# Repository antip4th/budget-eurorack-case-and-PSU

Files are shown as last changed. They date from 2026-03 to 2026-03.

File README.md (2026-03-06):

# budget-eurorack-case-and-PSU #
This repo contains all files to build your own budget 84HP Eurorack case with intrgrated bus board, PSU and an optional filter PCB.  

I made this, because of my limited budget as a student, I could not afford 250+€ 84HP cases and power supplies. Also I liked the idea to build stuff myself :)  

The case features two MeanWell PSUs, each of which supplies up to 3 A. This should be more than enough for a 84 HP case. Only +-12 V supplies, no +5 V. The cost is about 150 € max. Less, if you already have some cables and screws.

To remove the PSU output voltage spikes, I designed a custom filter PCB. It consists of one pi-filter per PSU [(see schematic)](PSU_filter_pcb/docs/psu_filter_schematic.pdf). It also can be built nicely on prototyping board instead of the PCB.

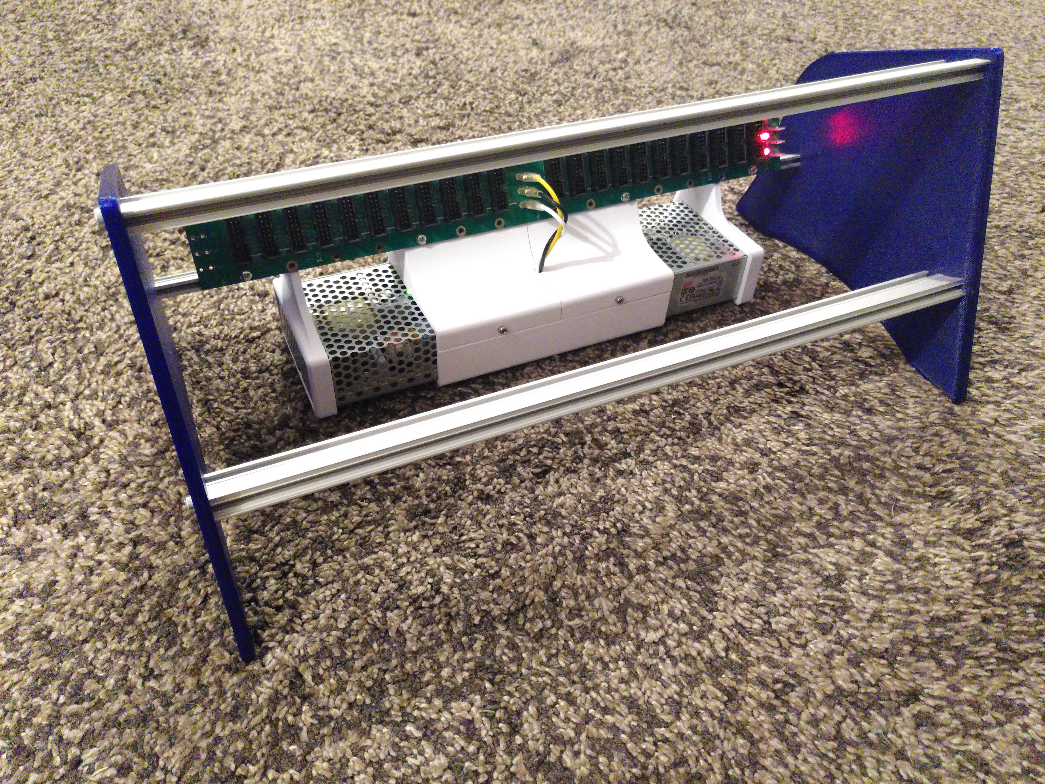
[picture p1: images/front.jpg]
Case front View


## Performance
The power supply together with the filter PCB can offer up to 3 A per power rail. In my setup I could only test with up to 2 A per rail. Because of the series resistance in the filter, at 2 A the supply voltage drops by about 120 mV. If tuning the PSU output voltage to slightly more than 12 V, the resulting voltage is still close to +-12 V, even under load. Some ripple switching voltage at around 500 Hz remains with about 10 mV peak to peak.  

## BOM Case ## 
|Part  |Quantity  |Price  (Feb. 2026)  | Link |
|---|---|---|---|
| Mean Well RS-35-12 PSU | 2 | 13.36 € | [DigiKey](https://www.digikey.de/en/products/detail/mean-well-usa-inc/RS-35-12/7706181) |
| Doepfer Bus board V6 | 1 | 40 € | [Schneidersladen](https://schneidersladen.de/en/doepfer-a-100-bus-board-v6) |
| 84HP eurorack rails with lip | 2 | 9 € | [Schneidersladen](https://schneidersladen.de/en/divers-sb-rail-19-with-lip) |
| 84 HP eurorack rails without lip | 1 | 10 € | [Schneidersladen](https://schneidersladen.de/en/divers-sb-rail-19-without-lip) |
| M3 slider nuts| 1 | 10 € | [Schneidersladen](https://schneidersladen.de/en/frap-tools-sliding-nuts-100-pcs) |
| Module Screws | 1 | 6 € | [Schneidersladen](https://schneidersladen.de/en/frap-tools-m3x6-philips-panhead-screws-silver-100-pieces) |
| M5x25 or M5x20 socket head screws | 6 | Included with rails if you order from Schneidersladen | [Amazon](https://a.co/d/07VXTLld) |
| | | ~ 8.00 € otherwise | |
| M3x6 socket head screw | 6 | | | 
| M3x5 button head screw | 2-8 | | |
| AC Cold appliances built-in plug | 1 | ~ 8 € | [Amazon](https://amzn.eu/d/06RYOiwI) |
| 0.75 mm²/18 AWG silicone cable | 1 m | 13 € | [Amazon](https://amzn.eu/d/0fPG9uPr) |
| Insulated cable lugs | 1 | 7 € | [Amazon](https://amzn.eu/d/0cKYAwAh) |
| Fork wire terminals | 1 | 7 € | [Amazon](https://amzn.eu/d/0jiY2vDV) |
| 3D-printed parts | | 3 € | |
| some heatshrink tubing | | | |
| SUM | | ~ 150 € worst case | |  

## BOM Filter PCB ##
|Part  |Quantity  |Price  (Feb. 2026)  | Link |
|---|---|---|---|
| Low ESR electrolytic caps 1000 µF | 4 | 0.5 € | [reichelt](https://www.reichelt.com/de/en/shop/product/elko_radial_1000_f_25_v_105_low_esr_12_5x20_mm_rm_5-166391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)|
| Ceramic caps 100 nF | 4 | 0.1 € | [reichelt](https://www.reichelt.com/de/en/shop/product/smd_multilayer_ceramic_capacitor_100_n_10_-22889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) |
| Ferrite core inductor 10 μΗ | 2 | 1 € | [reichelt](https://www.reichelt.com/de/en/shop/product/vertical_inductor_09hcp_ferrite_10_h-138644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) |
| Custom PCB or prototyping board | 1 | ~15 € if you have the PCB manufactured | |
| SUM | | ~ 20 € | |

## Build Instructions

### PCB

The soldering process is quite straight forward. I went for solder pads instead of terminal blocks to minimize contact resistance. Because of the big copper planes, for soldering the wires, I had to turn my soldering iron up to 450 °C.

<p align="center">
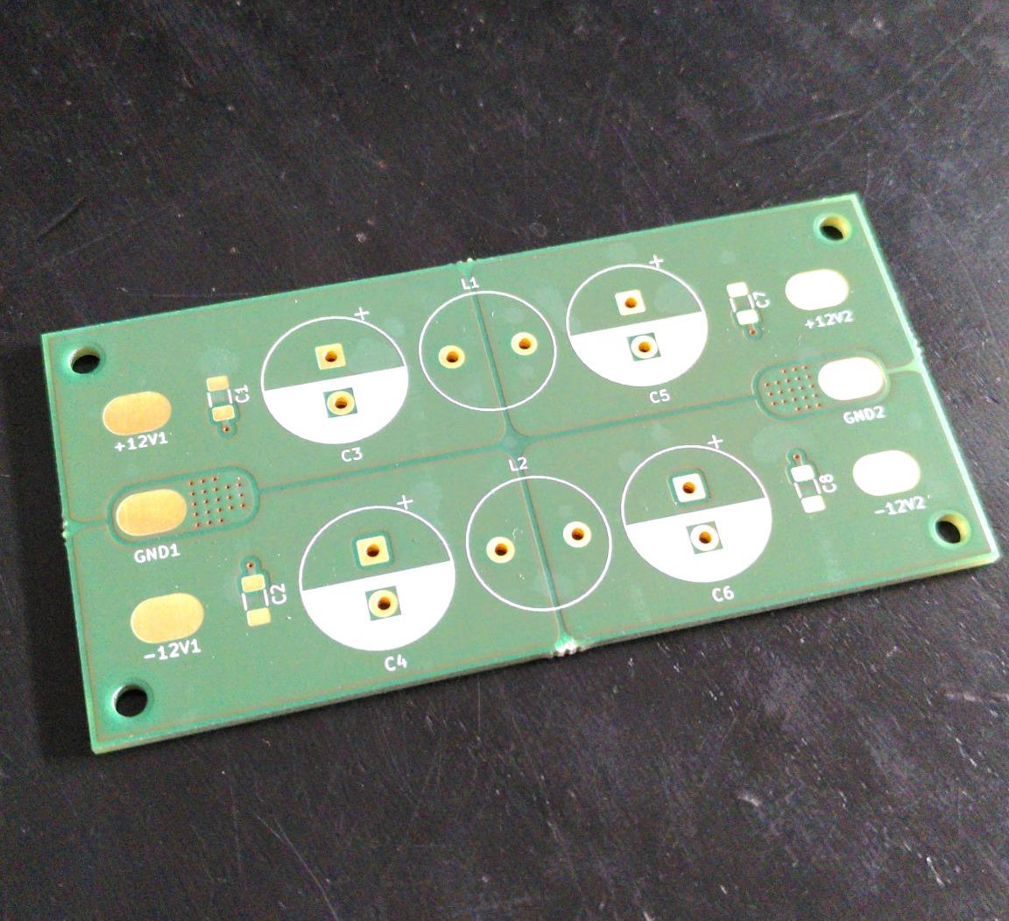
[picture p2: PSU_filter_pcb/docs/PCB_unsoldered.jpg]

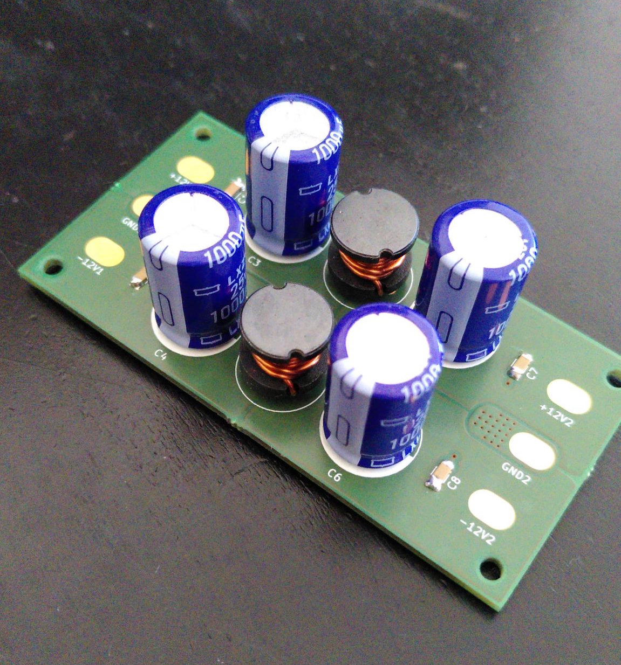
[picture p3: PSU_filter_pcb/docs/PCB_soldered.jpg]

</p>

<p align="center">

</p>

### Case

> [!CAUTION]
> This build requires wiring of mains power. Only work with mains voltage, if you know what you are doing!  
> Improper handling can cause electric shock, fire, or death. No liability is accepted for damage or injury.

1. The build starts with the wiring. The wire colors in this text correspond to the colors I used in my build and can be seen in the photos.
  1. Use the fork wire terminals to, connect the mains L (red), P (blue) and PE (green) terminals form the AC cold appliance socket with the respective terminals on both PSUs. The PSUs should be  connected to mains **in parallel**. You need to squeeze two cables into one cable lug.
  2. To get +-12 V outputs, the `-V` terminal of one of the PSUs is connected to the `+V` terminal of the other one. This node is the ground rail for the +-12 V outputs. I soldered both GND cables (black) onto the PCB's GND pad. If you don't use the PCB, directly crimp the bus board connector.
  3. The remaining `+V` output is the +12 V rail (yellow), and the remaining `-V` output is the -12 V rail (white). Either connect them to the PCB or crimp the connectors for the bus board directly.
  4. If you use the PCB, solder the cables on the output side and crimp the bus board connectors.

<p align="center">


</p>

2. Once the wiring is done, put everything together in the PSU case. Fix the PSUs to the case with the two screws on the bottom side. **Use short screws (<= 5mm) for this or you risk pushing the screw against the PCB inside the PSU!**

<p align="center">

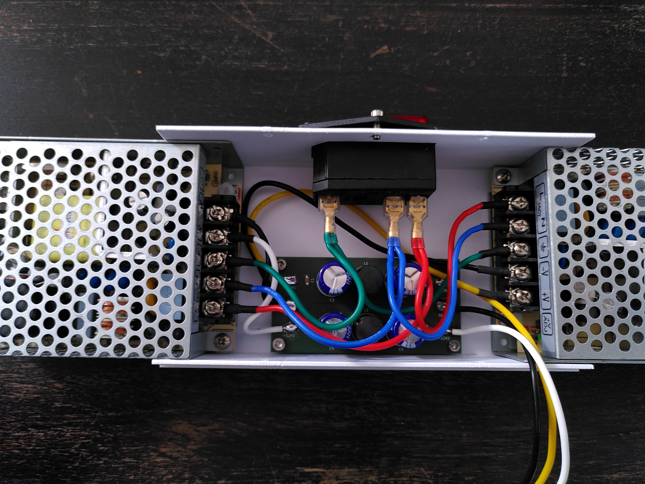
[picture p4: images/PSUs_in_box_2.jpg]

</p>

3. Attach the lid parts and the rib parts to the rail **without lip**. Use some of the screws and slider nuts for later fixing the position of the parts on the rail. 

<p align="center">
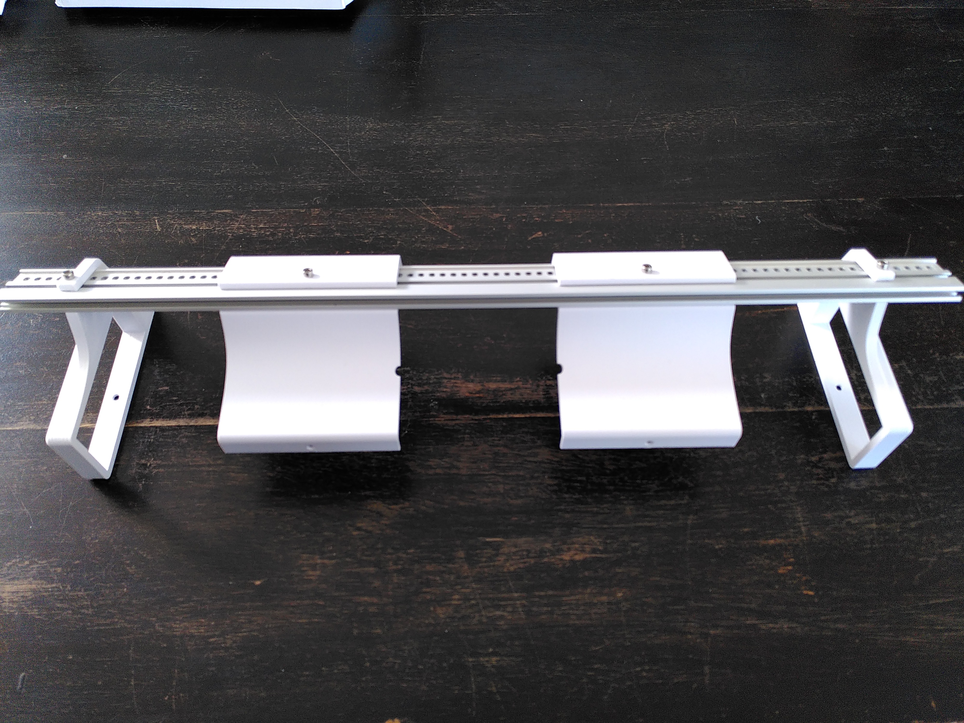
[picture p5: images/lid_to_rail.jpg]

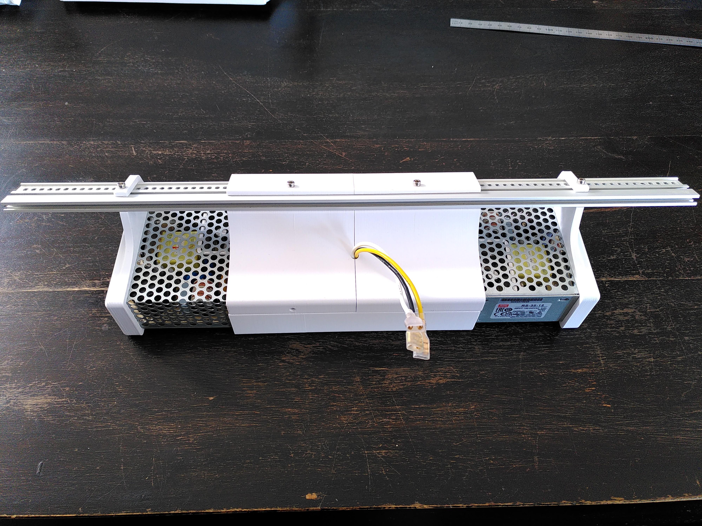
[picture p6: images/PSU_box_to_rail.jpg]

</p>

4. Attach the bus board to the rails with slider nuts. Put the ends of the PSUs into the ribs. Close everything up. Attach the side panels and the other rails and you're done!

<p align="center">
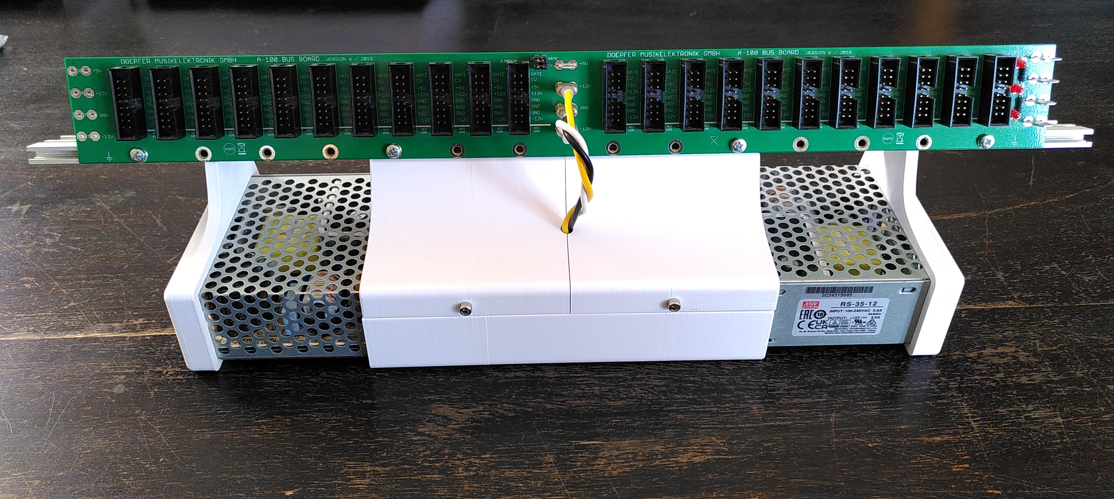
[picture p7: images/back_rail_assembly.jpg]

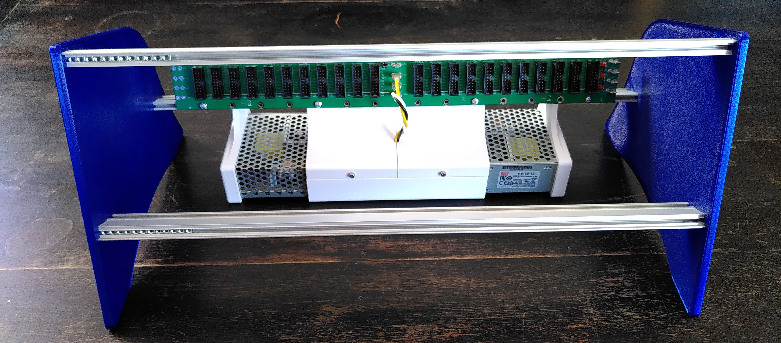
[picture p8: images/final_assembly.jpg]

</p>

## License

The contents of this repo are available under CERN OHL-S license.

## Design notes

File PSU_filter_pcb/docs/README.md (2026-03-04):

# README.md
This Project was generated with KiCad 9.0.7

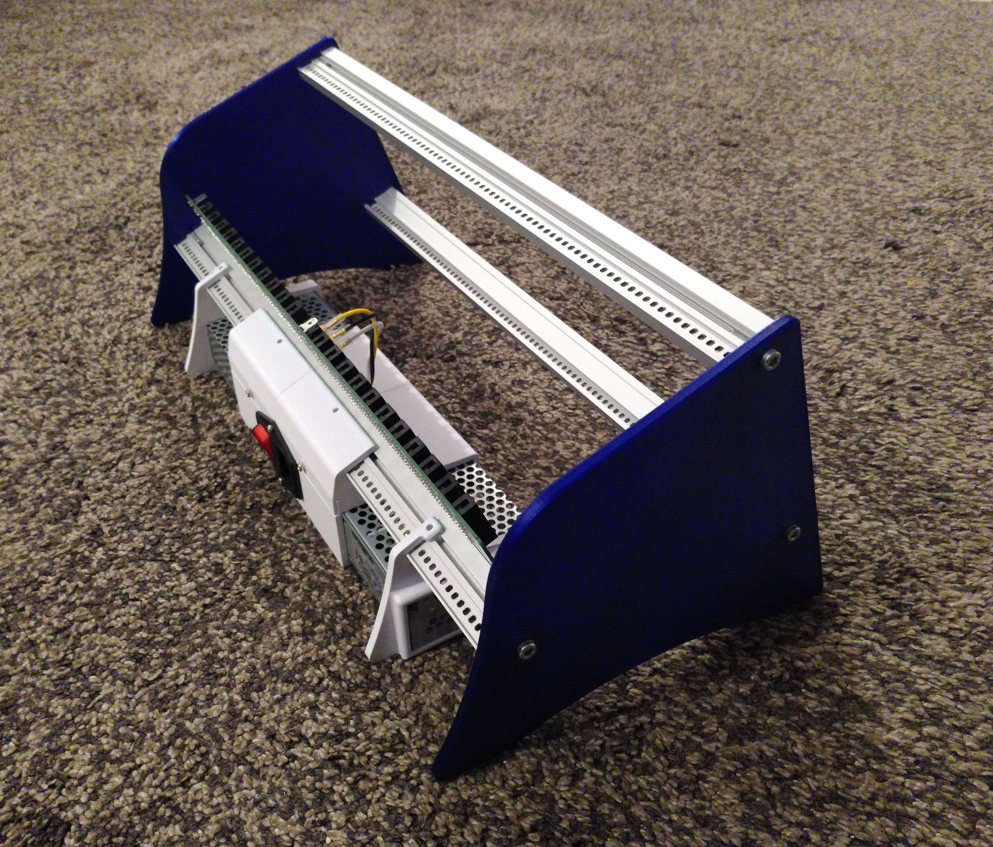
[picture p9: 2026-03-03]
images/rear_left.jpg

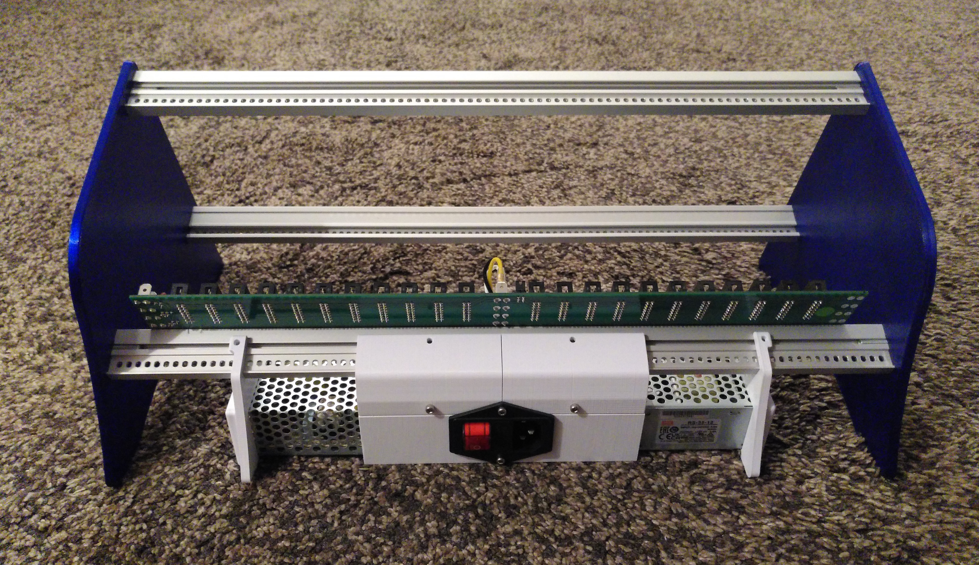
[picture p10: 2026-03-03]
images/rear.jpg

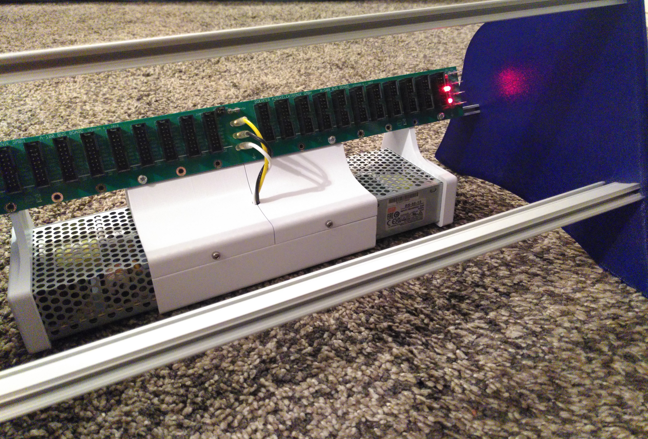
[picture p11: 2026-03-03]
images/front_closeup.jpg

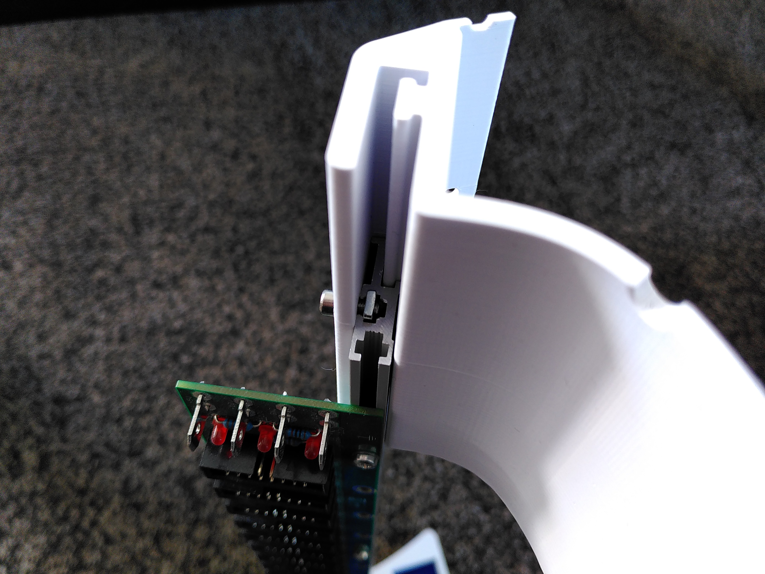
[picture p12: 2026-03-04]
images/lid_to_rail_nut.jpg

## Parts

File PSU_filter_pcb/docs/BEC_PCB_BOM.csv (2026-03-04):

Reference | Qty | Value | DNP | Exclude from BOM | Exclude from Board | Footprint | Datasheet
+12V1,+12V2,-12V1,-12V2,GND1,GND2 | 6 | TestPoint |  |  |  | Connector_Pad:WirePad_L6mm_W4mm | ~
C1,C2,C7,C8 | 4 | 100n |  |  |  | Capacitor_SMD:C_1206_3216Metric_Pad1.33x1.80mm_HandSolder | ~
C3,C4,C5,C6 | 4 | 1000u |  |  |  | Capacitor_THT:CP_Radial_D13.0mm_P5.00mm | ~
L1,L2 | 2 | 10u |  |  |  | Inductor_THT:L_Radial_D12.5mm_P7.00mm_Fastron_09HCP | ~

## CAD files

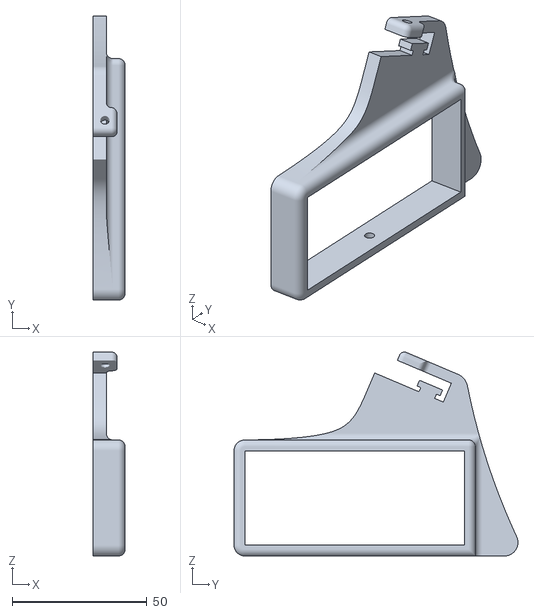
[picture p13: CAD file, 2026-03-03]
3d_print_parts/BudgetEurorackCase - PSURib.stl
12.0 x 105.3 x 75.6

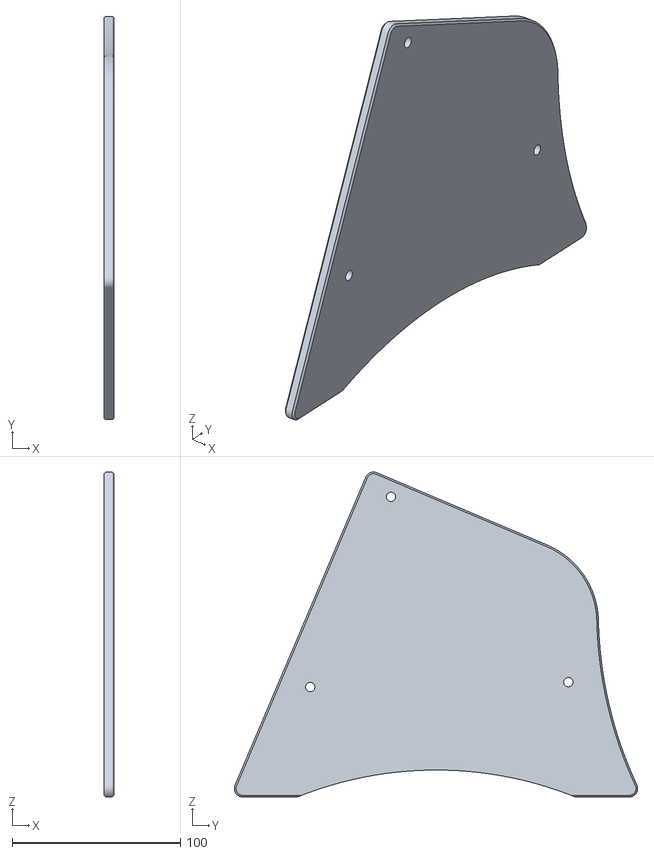
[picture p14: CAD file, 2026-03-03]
3d_print_parts/BudgetEurorackCase - sidePanel.stl
6.00 x 239.5 x 192.9

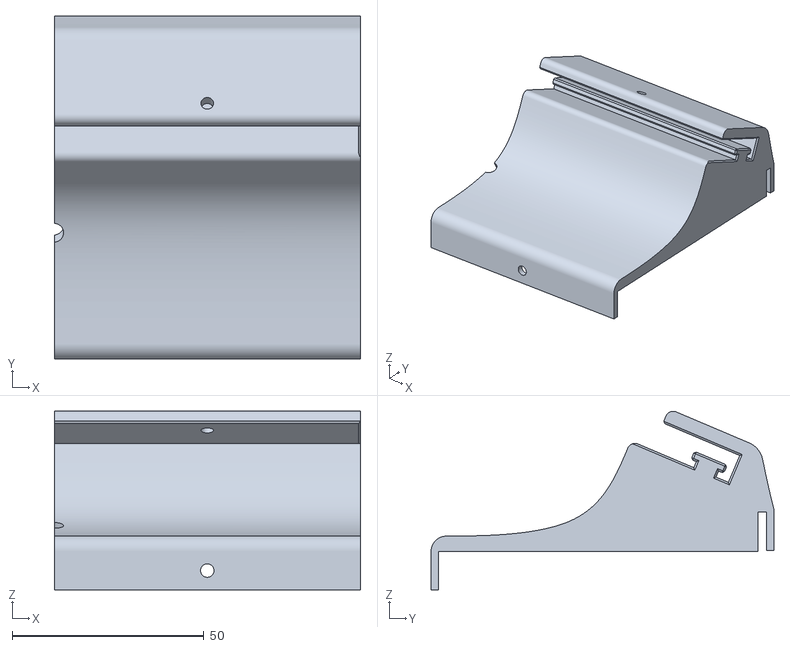
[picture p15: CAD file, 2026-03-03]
3d_print_parts/BudgetEurorackCase - PSUBoxLidRight.stl
79.9 x 89.5 x 46.6

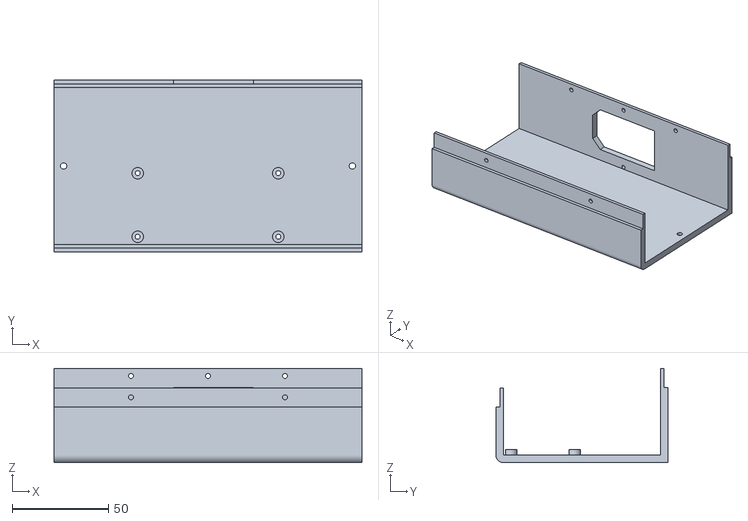
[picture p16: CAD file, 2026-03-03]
3d_print_parts/BudgetEurorackCase - PSUBoxBottom.stl
160.0 x 89.5 x 49.1

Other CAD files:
3d_print_parts/BudgetEurorackCase - PSUBoxLidLeft.stl

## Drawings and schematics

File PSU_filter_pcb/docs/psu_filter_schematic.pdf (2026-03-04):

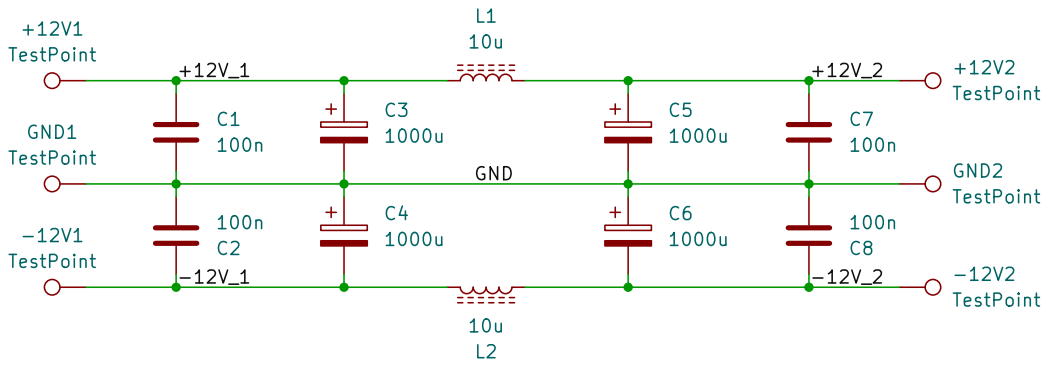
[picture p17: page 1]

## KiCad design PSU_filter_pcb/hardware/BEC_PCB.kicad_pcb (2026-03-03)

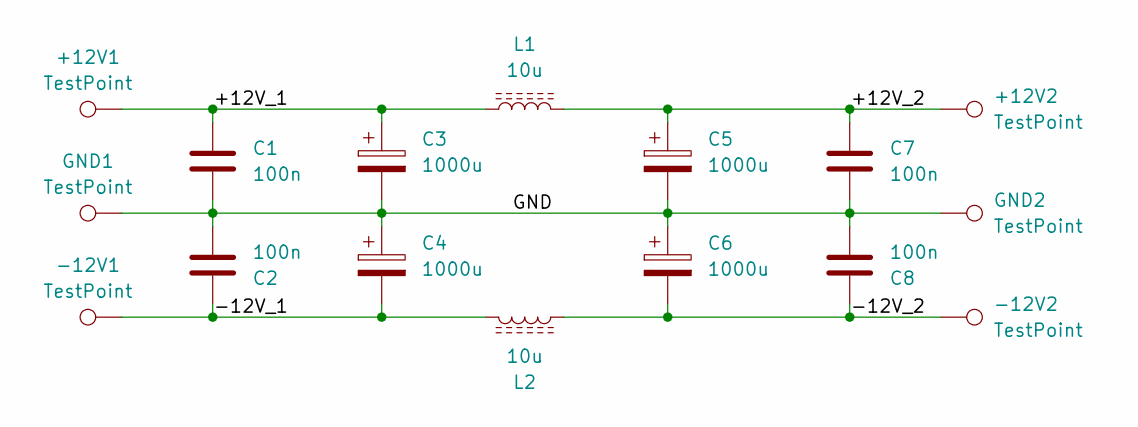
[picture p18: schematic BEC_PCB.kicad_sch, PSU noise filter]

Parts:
+12V1, +12V2: TestPoint; WirePad_L6mm_W4mm
-12V1, -12V2: TestPoint; WirePad_L6mm_W4mm
C1, C2, C7, C8: 100n; C_1206_3216Metric_Pad1.33x1.80mm_HandSolder
C3, C4, C5, C6: 1000u; CP_Radial_D13.0mm_P5.00mm
GND1, GND2: TestPoint; WirePad_L6mm_W4mm
L1, L2: 10u; L_Radial_D12.5mm_P7.00mm_Fastron_09HCP

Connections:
/+12V_1: +12V1.1, C1.1, C3.1, L1.1
/+12V_2: +12V2.1, C5.1, C7.1, L1.2
/-12V_1: -12V1.1, C2.1, C4.2, L2.1
/-12V_2: -12V2.1, C6.2, C8.1, L2.2
/GND: C1.2, C2.2, C3.2, C4.1, C5.2, C6.1, C7.2, C8.2, GND1.1, GND2.1

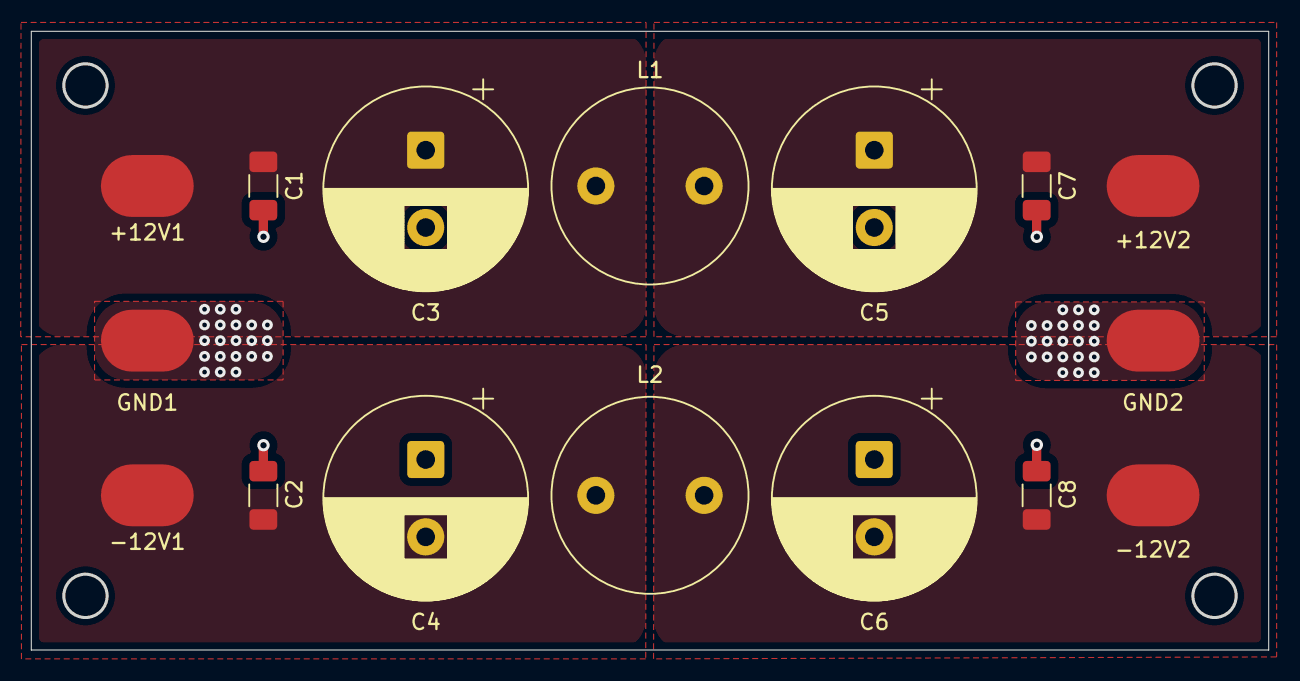
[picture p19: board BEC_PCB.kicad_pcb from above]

Board: 2 copper layers, 80.0 x 40.0 mm, 16 parts (0 on the bottom side), 5 nets.

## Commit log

2024-10-03 Created BOM
2026-03-02 Revise BOM entries and links in README
    Updated the Bill of Materials (BOM) with corrected items and links.
2026-03-02 Revise BOM with updated prices and links
    Updated the Bill of Materials (BOM) with new links and pricing.
2026-03-02 Enhance README with filter PCB and build details
    Updated README to include optional filter PCB and additional details about the build and BOM.
2026-03-02 Update README with bus board and filter PCB details
2026-03-02 Update README with BOM and cost details
    Added details about the cost and components for the Eurorack case and filter PCB.
2026-03-02 Update BOM Filter PCB with prices and links
2026-03-03 Fix typo in README about case features
    Corrected a typo in the description of the case features.
2026-03-03 Clarify cost for custom PCB in README
    Updated the cost description for the custom PCB or prototyping board.
2026-03-03 upload project files
    [BEC_PCB.kicad_pcb, BEC_PCB.kicad_sch, BudgetEurorackCase - PSUBoxBottom.stl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]
2026-03-04 add schematic pdf
2026-03-04 add bom csv
    [BEC_PCB_BOM.csv]
2026-03-04 removed rail STLs
    [BudgetEurorackCase - railWithLip.stl, BudgetEurorackCase - railWithoutLip.stl]
